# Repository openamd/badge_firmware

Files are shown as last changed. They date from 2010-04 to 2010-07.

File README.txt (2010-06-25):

This project is that of the Next Hope conference's badge, a descendant
of the OpenBeacon Sputnik and Last Hope Badge designs.  An NRF24L01+
radio is connected to either an MSP430F2618 or MSP430F2418 in 80LQFP
or 64LQFP packaging.

For the conference itself, the badge has its FT232RL and USB connector
unpopulated.  These can be added to facilitate MSP430 development on
the badge, such as packet sniffing and injection on the 2.4GHz ISM
band.  For more casual users, an FTDI cable ought to suffice.

The MSP430's bootloader in hardware, so you needn't worry about
bricking the device.  Use a BSL client with 2xx support, such as
goodfet.bsl from http://goodfet.sf.net/ .

Happy Hacking,
--Travis Goodspeed

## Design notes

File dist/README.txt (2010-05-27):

==========================================================
README

This README was built for manufacturing, not for development.  The
following instructions explain how to program the badge from a Windows
workstation with a single GoodFET programmer attached.

-q@theqlabs.com

==========================================================

Hold the Windows button down and press the "R" key
Type "cmd" and press ENTER
type "cd dist" and press ENTER

THEN ...

======================
Drivers
======================

Install vcredist_x86.exe if the "Cannot execute program." error
message is seen.  Drivers for the FTDI chip in the GoodFET programmer
can be found in CDM*.ZIP.

All of these files are in the Drivers folder.

======================
TO SCAN FOR PROGRAMMER
======================

Type "scan.bat" and press ENTER.

NOTE: Scanning is now automatically handled in the other commands.  Just
make sure that one COM port is listed, such as

COM6: (FTDIBUS\COMPORT&VID_0403&PID_6001) Ready

=======================
TO FLASH THE PROGRAMMER
=======================

Type "flashProgrammer.bat" and press ENTER.  This will load the latest
programmer firmware, which is necessary to program the badge.

====================
BADGE BLINK TEST
====================

Type "flashBlink.bat" and press ENTER.  This will blink LED1 and do
nothing else.  This is only to verify that the programmer is properly
wired.

==================
BADGE RADIO TEST
==================

Type "flashBadge.bat" and press ENTER.  This will update the badge
firmware.  You will be asked for a serial number, which should be
between 5,000 and 7,000.

LED1 will blink each time a packet is sent over the radio.  At the
same time, a radio chirp should be seen on 2.481 GHz.  You will also
notice all three leds responding to finger presses on the 8-pin GPIO
header.

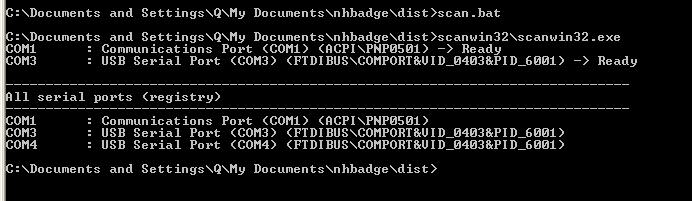
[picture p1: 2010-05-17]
dist/scanExampleImage.JPG

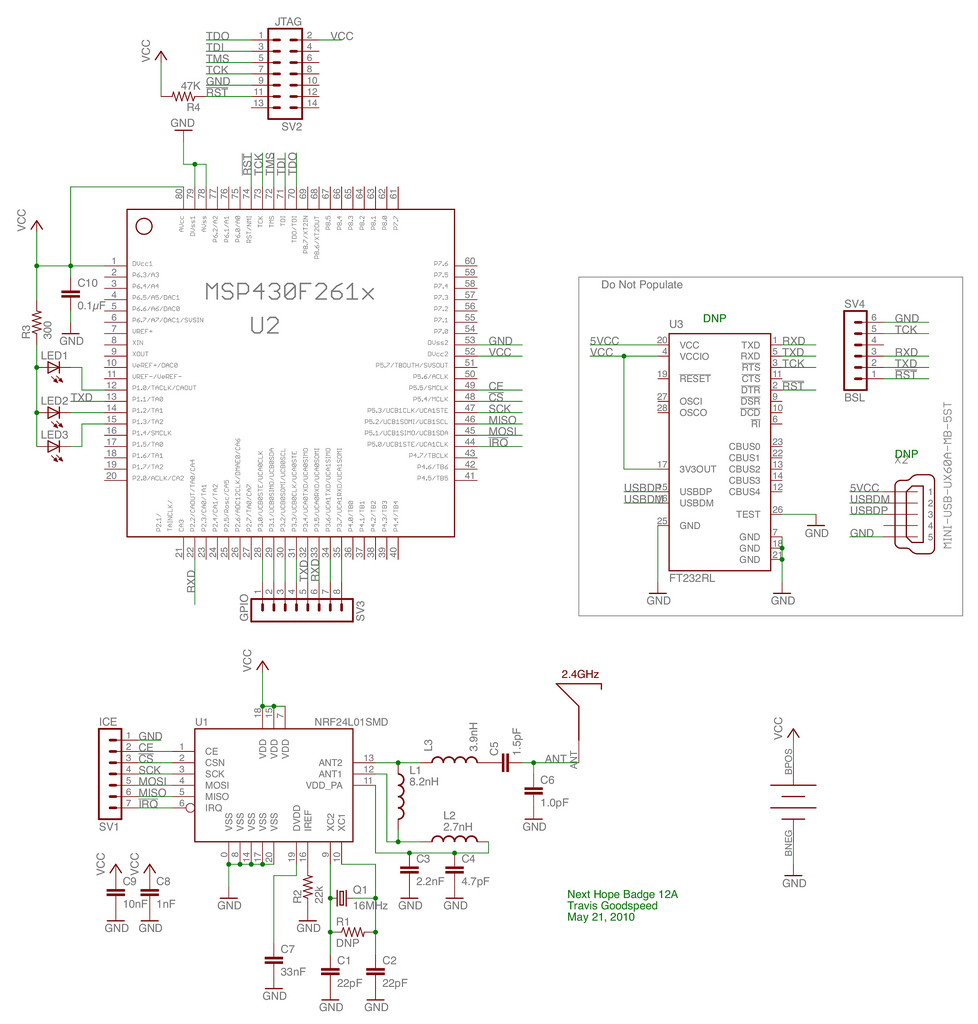
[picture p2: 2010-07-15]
web/nhb12a_schem.jpg

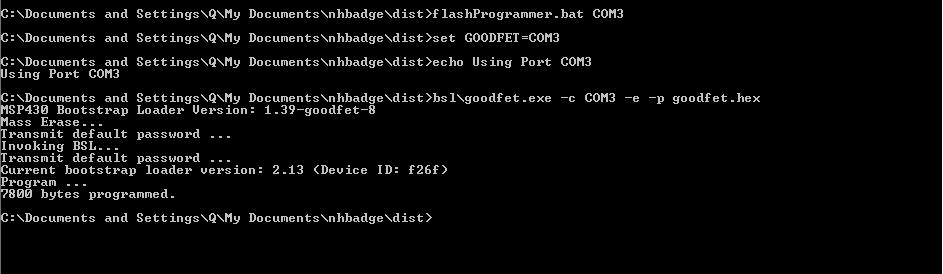
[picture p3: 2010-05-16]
dist/flashProgrammerExampleImage.JPG

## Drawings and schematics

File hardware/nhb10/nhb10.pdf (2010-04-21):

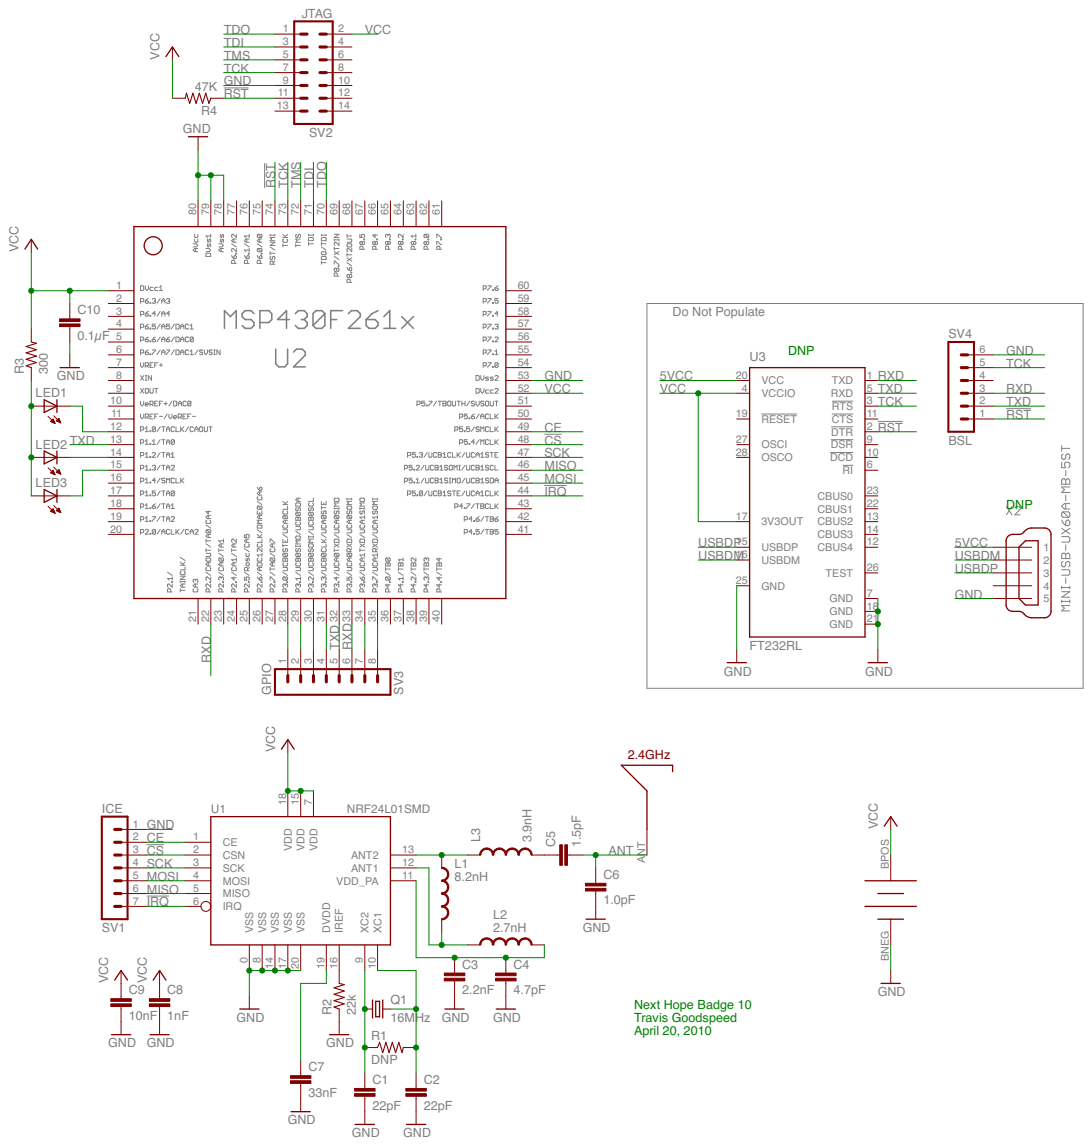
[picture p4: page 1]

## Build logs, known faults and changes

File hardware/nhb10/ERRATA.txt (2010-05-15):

Mext Hope Badge 1.0 Errata
by Travis Goodspeed

ERRATUM 1.

Pin 80 of U2 is AVcc.  It should not be run to ground.  Lift the pin
to correct.

ERRATUM 2.

The battery is located too close to the JTAG port.  Fixed in NHB11 by
moving it further North.

ERRATUM 3.

The programmers shipped to Shanghai with firmware that is not
compatible with the new MSP430 chips.  New firmware needs to be
flashed, and a new client needs to be used.

ERRATUM 4.

The TEST pin of the FTDI should be tied to GND.  Leaving it floating
makes the device non-functional unless you are lucky enough to have a
solder bridge.

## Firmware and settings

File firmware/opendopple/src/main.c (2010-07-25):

/***************************************************************
 *
 * OpenBeacon.org - main entry, CRC, behaviour
 *
 * Copyright 2006 Milosch Meriac <meriac@openbeacon.de>
 * Ported to MSP430 by Travis Goodspeed <travis@tnbelt.com>
 *
 ***************************************************************/

/*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
    You should have received a copy of the GNU General Public License along
    with this program; if not, write to the Free Software Foundation, Inc.,
    51 Franklin Street, Fifth Floor, Boston, MA 02110-1301 USA.

*/

#define OPENBEACON_ENABLEENCODE

//#include <htc.h> //PICC thing
#include <stdlib.h>
#include "config.h"
#include "timer.h"
#include "xxtea.h"
#include "nRF_CMD.h"
#include "nRF_HW.h"
#include "main.h"
#include "led.h"

#ifndef OID_CODE
  #define OID_CODE 0xbeef1337
#endif

//Missing macros.
//__CONFIG (0x03d4);
//__EEPROM_DATA (0x00, 0x00, 0x00, 0x00, 0x00, 0x00, 0x00 ,0x00);

volatile /* const */ u_int32_t oid = OID_CODE, seed = 0xFFFFFFFF;
u_int32_t seq = 0;
static u_int16_t code_block;

TMacroBeacon g_MacroBeacon = {
  0x02,				// Size
  RF_SETUP | WRITE_REG,		// Setup RF Options
  RFB_RFOPTIONS,

  sizeof (TBeaconEnvelope) + 1,	// Size
  WR_TX_PLOAD			// Transmit Packet Opcode
};

//! Swap byte order of a long.
unsigned long htonl (unsigned long src)
{
  unsigned long res;

  ((unsigned char *) &res)[0] = ((unsigned char *) &src)[3];
  ((unsigned char *) &res)[1] = ((unsigned char *) &src)[2];
  ((unsigned char *) &res)[2] = ((unsigned char *) &src)[1];
  ((unsigned char *) &res)[3] = ((unsigned char *) &src)[0];

  return res;
}

//! Swap byte order of a short.
unsigned short htons (unsigned short src)
{
  unsigned short res;

  ((unsigned char *) &res)[0] = ((unsigned char *) &src)[1];
  ((unsigned char *) &res)[1] = ((unsigned char *) &src)[0];

  return res;
}

#define SHUFFLE(a,b) 	tmp=g_MacroBeacon.env.datab[a];\
			g_MacroBeacon.env.datab[a]=g_MacroBeacon.env.datab[b];\
			g_MacroBeacon.env.datab[b]=tmp;

void shuffle_tx_byteorder (void) {
  unsigned char tmp;

  SHUFFLE (0 + 0, 3 + 0);
  SHUFFLE (1 + 0, 2 + 0);
  SHUFFLE (0 + 4, 3 + 4);
  SHUFFLE (1 + 4, 2 + 4);
  SHUFFLE (0 + 8, 3 + 8);
  SHUFFLE (1 + 8, 2 + 8);
  SHUFFLE (0 + 12, 3 + 12);
  SHUFFLE (1 + 12, 2 + 12);
}

unsigned short crc16 (const unsigned char *buffer, unsigned char size){
  unsigned short crc = 0xFFFF;
  if (buffer) {
    while (size--) {
      crc = (crc >> 8) | (crc << 8);
      crc ^= *buffer++;
      crc ^= ((unsigned char) crc) >> 4;
      crc ^= crc << 12;
      crc ^= (crc & 0xFF) << 5;
    }
  }
  return crc;
}

void dopplegang();

void store_incremented_codeblock (void) {
  if (code_block < 0xFFFF) {
    code_block++;
    //EEPROM_WRITE (0, (u_int8_t) (code_block));
    sleep_jiffies (10 * TIMER1_JIFFIES_PER_MS);
    //EEPROM_WRITE (1, (u_int8_t) (code_block >> 8));
    sleep_jiffies (10 * TIMER1_JIFFIES_PER_MS);
  }
}

//TODO move this to a separate header.
void msp430_init_dco();

//! Returns 1 if NRF is connected.
int nrf_ready(){
  char channel=81;
  nRFCMD_RegWrite(5,&channel,1);
  channel=12;
  nRFCMD_RegRead(5,&channel,1);
  
  return channel==81;
}


int openbeacon();

int main (){
  // Stop WDT
  WDTCTL = WDTPW + WDTHOLD;
  
  //LED setup
  PLEDDIR=LEDBITS;
  PLED|=LEDBITS;
  
  PDIR=MOSI+SCK+CSN+CE;//Radio outputs
  POUT=CSN; //chip unselected, radio off.
  
  //Load OID from Info Flash
  // oid=((long*) 0xFFB0)[0];
  oid = OID_CODE;  

  do{
    LED1_LIT;
    LED2_LIT;
    LED3_LIT;
    nRFCMD_Init ();
  }while(!nrf_ready());
  led_startup();
  
  
  //Start broadcasting.
  openbeacon();

  return 0;
}


//! Entry point to the openbeacon app.
int openbeacon(){
  u_int8_t i, status;
  u_int16_t crc=0;
  u_int8_t oldp3=0xFF;
  
  nRFCMD_Init ();
  
  
  // increment code block after power cycle
  ((unsigned char *) &code_block)[0] = EEPROM_READ (0);
  ((unsigned char *) &code_block)[1] = EEPROM_READ (1);
  store_incremented_codeblock ();

  seq = crc ^ oid ^ seed;
  srand (crc16 ((unsigned char *) &seq, sizeof (seq)));

  // increment code blocks to make sure that seq is higher or equal after battery
  // change
  seq = 0; //((u_int32_t)(code_block-1)) << 16;

  i = 0;
  //if (code_block != 0xFFFF)  //Adds security.
    while (1){
      //Step transmit power.
      g_MacroBeacon.rf_setup = NRF_RFOPTIONS | ((i & 3) << 1);
      g_MacroBeacon.env.pkt.hdr.size = sizeof (TBeaconTracker);
      
      g_MacroBeacon.env.pkt.hdr.proto = RFBPROTO_BEACONTRACKER;
      // TODO g_MacroBeacon.env.pkt.flags = CONFIG_PIN_SENSOR ? 0 : RFBFLAGS_SENSOR;
      //g_MacroBeacon.env.pkt.flags = P3IN;
      //Strength field, also describes TX power.
      g_MacroBeacon.env.pkt.strength = 0x55 * (i & 0x3);
      g_MacroBeacon.env.pkt.seq = htonl (seq++);
      g_MacroBeacon.env.pkt.oid = htonl (oid);
      g_MacroBeacon.env.pkt.reserved = CALBC1_16MHZ|(CALDCO_16MHZ<<8);
      crc = crc16 (g_MacroBeacon.env.datab,
		   sizeof (g_MacroBeacon.env.pkt) -
		   sizeof (g_MacroBeacon.env.pkt.crc));
      g_MacroBeacon.env.pkt.crc = htons (crc);
      
      /*
      g_MacroBeacon.env.pkt.hdr.size = ((char*) &g_MacroBeacon.env.pkt)[-1];
      ((char*) &g_MacroBeacon.env.pkt)[-1]=0xde;
      */
      
      // update code_block so on next power up
      // the seq will be higher or equal
      crc = seq >> 16;
      if (crc == 0xFFFF)
	break;
      if (crc == code_block)
	store_incremented_codeblock ();
      
      // encrypt my data
      #ifdef CONFIG_TEA_ENABLEENCODE
      shuffle_tx_byteorder ();
      xxtea_encode ();
      shuffle_tx_byteorder ();
      #endif
      
      
      // Indicate touch sensor.  This must be done before P3 refresh below.
      LED1_DIM;
      LED2_DIM;
      LED3_DIM;
      
      // Multitouch! (strong)
      /*
      if((P3IN^0xFF)&0xC0)
	LED3_LIT;
      if((P3IN^0xFF)&0x18)
	LED2_LIT;
      if((P3IN^0xFF)&0x03)
	LED1_LIT;
      */
      
      
      
      //Reset touch sensor.
      P3OUT=0xFF;
      P3DIR=0xFF;
      
      //Capacitance will change to show status.
      msleep(3);
      P3DIR=0;
      msleep(3);
      
      oldp3=P3IN;
      g_MacroBeacon.env.pkt.flags = oldp3;
      // Multitouch! (strong)
      /* if((oldp3^0xFF)&0x80) */
      /* 	LED3_LIT; */
      /* if((oldp3^0xFF)&0x18) */
      /* 	LED2_LIT; */
      /* if((oldp3^0xFF)&0x01) */
      /* 	LED1_LIT; */
      
      
      //Sleep for a bit while I/O is outbound.
      msleep(1+(rand()&0x3F)); //Bitmasking works, modulus doesn't.  Sign extension?
      
      // send it away
      nRFCMD_Macro ((unsigned char *) &g_MacroBeacon);
      status = (i & 0x7) == 0;
      

      if(status)
	LED1_LIT;
      nRFCMD_Execute (); //Transmit packet held in TX Buffer

      while(!nrf_ready()){
	nRFCMD_Init ();  //Reset radio.
	LED3_LIT;
      }


      if ((oldp3^0xFF)&0x80) {
	dopplegang();
      }
      nRFCMD_Init ();
      
      i++;
    }
  
  // rest in peace
  // when seq counter is exhausted
  LED1_DIM;
  LED2_DIM; 
  LED3_DIM;
  while (1){
    sleep_jiffies (95 * TIMER1_JIFFIES_PER_MS);
    //LED3_LIT;
    sleep_jiffies (5 * TIMER1_JIFFIES_PER_MS);
    //LED3_DIM;
  }
}

//! Macro to receive a packet.
const unsigned char g_MacroRecv[] = {
  0x02, CONFIG | WRITE_REG, NRF_CONFIG_PRIM_RX | NRF_CONFIG_PWR_UP,
  //0x02, STATUS | WRITE_REG, 0x70,	// reset status
  0x00
};


void selftest_body();

//! Alternate reset vector for testing radio.
interrupt(RESERVED0_VECTOR)  //Entry point at 0xFFC0 on MSP430F2618.
selftest_main(){
  //Start stack, because we aren't coming from main().
  asm("mov     #0x3000, r1");
  selftest_body();
}

//! Tests for radio reception, then moves the results into the PC.
void selftest_body(){
  u_int8_t i;
  u_int8_t* packet=(u_int8_t*) 0x3000;  //Packets are stored here.
  u_int8_t status;
  int rxcount=0;
  
  //Blank testing area.
  for(i=0;i<0xff;i++)
    packet[i]=0;
  packet=(u_int8_t*) 0x3020;
  
  // Stop WDT
  WDTCTL = WDTPW + WDTHOLD;
  
  //LED setup
  PLEDDIR=LEDBITS;
  PLED|=LEDBITS;
  
  //Pin directions
  PDIR=MOSI+SCK+CSN+CE;//Radio outputs
  POUT=CSN; //chip unselected, radio off.
  
  
  //Enter receiver mode.
  nRFCMD_InitSniff ();
  nRFCMD_Macro ((unsigned char *) &g_MacroRecv);
  
  
  //Set bytes to 0xFF that must be zero.
  packet[0]=0xFF;
  
  i = 0;
  LED1_DIM;
  while (1){
    
    //Enter receiver mode.
    nRFCMD_InitSniff ();
    nRFCMD_Macro ((unsigned char *) &g_MacroRecv);
  
    
    //Wait a bit.
    LED3_DIM;
    POUT|=CE;
    msleep(300L); //0.1s
    POUT&=~CE;
    LED3_LIT;
    
    
    POUT|=CE;
    //Get the packet.
    POUT&=~CSN;
    nRFCMD_XcieveByte(RD_RX_PLOAD);
    for(i=0;i<16;i++)
      nRFCMD_XcieveByte(0xde);
    POUT|=CSN;

    nRFCMD_RegRead(STATUS,&status,1);
    if(status&0x40){
      // Clear the packet.
      if(rxcount++>3)
	packet[0]=0;
      
      // Clear the flag.
      status=0x40;
      nRFCMD_RegWrite(STATUS,&status,1);
      // Blink led.
      P1OUT^=1;
      // Flush buffer.
      nRFCMD_RegRead(0xE2,&status,0);
      LED2_LIT;
    }
    
  }
}


void dopplegang() {
  u_int8_t i;
  u_int8_t* packet=(u_int8_t*) 0x3000;  //Packets are stored here.
  u_int8_t status;
  int rxcount=0;

  // Stop WDT
  WDTCTL = WDTPW + WDTHOLD;

  //Blank testing area.
  //for(i=0;i<0xff;i++)
  //  packet[i]=0;
  packet=(u_int8_t*) 0x3020;

  LED3_LIT;
  //Enter receiver mode.
  nRFCMD_InitSniff ();
  nRFCMD_Macro ((unsigned char *) &g_MacroRecv);
  
  //Set bytes to 0xFF that must be zero.
  packet[0]=0xFF;
  
  i = 0;
      
  POUT|=CE;
  msleep(300L); //0.1s
  POUT&=~CE;
    
  POUT|=CE;
  //Get the packet.
  POUT&=~CSN;
  nRFCMD_XcieveByte(RD_RX_PLOAD);
  for(i=0;i<16;i++)
    packet[i]=nRFCMD_XcieveByte(0xde);
  POUT|=CSN;
  
  
  // Who are you?  You, it so happens, are me.
  oid = ((uint32_t)packet[11] & 0xff) | 
    ((uint32_t)packet[10] & 0xff) << 8 |
    ((uint32_t)packet[9] & 0xff) << 16 | 
    ((uint32_t)packet[8] & 0xff) << 24;

  // If we didn't dup the sequence number, we'd
  // be too easy to mine after the fact.
  seq = ((uint32_t)packet[7] & 0xff) | 
    ((uint32_t)packet[6] & 0xff) << 8 |
    ((uint32_t)packet[5] & 0xff) << 16 | 
    ((uint32_t)packet[4] & 0xff) << 24;

  LED3_DIM;
}

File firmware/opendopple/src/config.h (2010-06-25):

/***************************************************************
 *
 * OpenBeacon.org - configuration file
 *
 * Copyright 2006 Milosch Meriac <meriac@openbeacon.de>
 * Modifications in 2010 by Travis Goodspeed <travis at radiantmachines.com>
 *
 ***************************************************************/

/*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
    You should have received a copy of the GNU General Public License along
    with this program; if not, write to the Free Software Foundation, Inc.,
    51 Franklin Street, Fifth Floor, Boston, MA 02110-1301 USA.
    	
*/

#include <signal.h>
#include <io.h>
#include <iomacros.h>


#ifndef CONFIG_H
#define CONFIG_H

#define	CONFIG_DEBUG_LED
#define CONFIG_DELAYUS


//TEA is off for now.
//#define CONFIG_TEA_ENABLEENCODE
//#define CONFIG_TEA_ENABLEDECODE

/***************************************************************
 *
 *  CPU peripherals settings
 *
 * configuration:
 *      RA0                     input
 *      RA1     SENSOR          input
 *      RA2     nRF_IRQ         input
 *      RA3     Vpp             input
 *      RA4                     input
 *      RA5                     input
 *
 *      RC0     SCK             output
 *      RC1     MOSI            output
 *      RC2     MISO            input
 *      RC3     CSN             output
 *      RC4     nRF_CE          output
 *      RC5     LED             output
 *
 ***************************************************************/

/*
// PIC pins are weird.  This is deprecated.
#define CONFIG_PIN_SENSOR	RA1
#define CONFIG_PIN_IRQ		RA2

#define CONFIG_PIN_SCK		RC0
#define CONFIG_PIN_MOSI		RC1
#define CONFIG_PIN_MISO		RC2
#define CONFIG_PIN_CSN		RC3
#define CONFIG_PIN_CE		RC4
#define CONFIG_PIN_LED		RC5

#define CONFIG_CPU_XTAL_FREQ	8MHz
#define CONFIG_CPU_TRISA	0x3F
#define CONFIG_CPU_TRISC	0x04
#define CONFIG_CPU_ANSEL	0x00
#define CONFIG_CPU_WPUA		0x02
#define CONFIG_CPU_CMCON0	0x07
#define CONFIG_CPU_OPTION	0x00
#define CONFIG_CPU_OSCCON	0x71
*/

#define PLED P1OUT
#define PLEDDIR P1DIR
#define LEDBITS (BIT0+BIT2+BIT3);
#define LED1_LIT P1OUT&=~BIT0
#define LED2_LIT P1OUT&=~BIT2
#define LED3_LIT P1OUT&=~BIT3
#define LED1_DIM P1OUT|=BIT0
#define LED2_DIM P1OUT|=BIT2
#define LED3_DIM P1OUT|=BIT3


//Pins and I/O
#define IRQ   BIT0
#define MOSI BIT1
#define MISO BIT2
#define SCK  BIT3
#define CSN BIT4
#define CE BIT5


#ifdef p4
#define POUT P4OUT
#define PDIR P4DIR
#define PREN P4REN
#define PIN P4IN
#endif

#ifdef p5
#define POUT P5OUT
#define PDIR P5DIR
#define PREN P5REN
#define PIN P5IN
#endif

// Port definitions, replacing PICC ones.
#define CONFIG_PIN_CSN_HIGH POUT|=CSN
#define CONFIG_PIN_CSN_LOW POUT&=~CSN
#define CONFIG_PIN_CE_HIGH POUT|=CE
#define CONFIG_PIN_CE_LOW POUT&=~CE
#define CONFIG_PIN_MOSI_HIGH POUT|=MOSI
#define CONFIG_PIN_MOSI_LOW POUT&=~MOSI
#define CONFIG_PIN_SCK_HIGH POUT|=SCK
#define CONFIG_PIN_SCK_LOW POUT&=~SCK
#define CONFIG_PIN_MISO (PIN&MISO?1:0)

// TODO fix EEPROM stuff to use info B.
#define EEPROM_READ(x) (0)

/***************************************************************
 *
 *  RF chip settings
 *
 ***************************************************************/

#define CONFIG_DEFAULT_CHANNEL 81

#endif

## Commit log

2010-03-10 NHB10 radio layout.
    [nhb10.sch]
2010-03-10 README file.
    [nhb10.sch]
2010-03-10 About to route the radio.
    [nhb10.brd]
2010-03-10 Routed, about to draw ground planes.
    [nhb10.brd]
2010-03-10 Mostly routed, planes next.
    [nhb10.brd]
2010-04-08 Radio layout complete.
    [nhb10.brd, nhb10.sch]
2010-04-08 MSP430 routed.
    [nhb10.brd, nhb10.sch]
2010-04-08 Optional FT232RL
    [nhb10.brd, nhb10.sch]
2010-04-09 real battery clip.
2010-04-19 badge library
    [nhb10.brd, nhb10.sch]
2010-04-20 Trace antenna complete.
2010-04-20 Trace antenna routed.
    [nhb10.brd, nhb10.sch]
2010-04-20 More vias.
    [nhb10.brd]
2010-04-20 Circle shape, drill hole, extended ground plane.
    [nhb10.brd, nhb10.sch]
2010-04-20 Circle, lanyard hole.
    [nhb10.brd, nhb10.sch]
2010-04-20 Sending for fab.
    [nhb10.brd]
2010-04-21 PDF schematic.
2010-04-21 Centroid file for pick-and-place.
    [nhb10 centroid.csv]
2010-04-21 FTDI cable and PCB Antenna datasheets.
2010-05-06 About to fork timer.c
2010-05-06 Getting closer, just timer.c to go.
2010-05-06 It compiles! Timer not quite right.
2010-05-14 Forked badge for NHB11.
    [nhb11.brd, nhb11.sch]
2010-05-15 NHB10 errata, NHB11 layout.
    [nhb11.brd, nhb11.sch]
2010-05-16 BSL target, fixing the timing.
    [config.h, main.c, msp430x2618.c]
2010-05-16 Timing is all kinds of wrong, but this works.
    [main.c]
2010-05-16 BSL uses comport as specified, erases FET.
2010-05-17 Drivers for Windows.
2010-05-17 Drivers instructions.
2010-05-21 NHB11 gerbers.
    [nhb11.brd, nhb11.sch]
2010-05-21 Forked NHB11 to NHB11b for 64-pin chips.
    [nhb11b.brd, nhb11b.sch]
2010-05-21 NHB11b routed.
    [nhb11b.brd, nhb11b.sch]
2010-05-21 Ready to fab NHB11b.
    [nhb11b.brd, nhb11b.sch]
2010-05-21 NHB11b gerbers.
2010-05-21 11a label.
    [nhb11.sch]
2010-05-23 Fancier LED artwork, longer broadcasts.
2010-05-26 Added __attribute__((packed)) to the packet to prevent 16-bit packing problems.
    [main.c]
2010-05-26 Multitouch works, timer is still a bit wonky.
2010-05-26 Cleaned warnings, removed PIC timer code.
2010-05-26 Multitouch works, timer too.
2010-05-30 Low power mode, proper 2618 erase. A GoodFET patch for the info memory bit might be needed.
2010-05-30 Low power mode works!
2010-05-30 Less sensitive LED. Working on proper sensitivity.
2010-05-30 Sequences now always start at zero and code_block check is skipped. These won't be necessary at TNH unless we change our mind about crypto.
    [main.c]
2010-05-31 NHB12 fork.
    [nhb12.brd, nhb12.sch]
2010-05-31 NHB12B Rename.
    [nhb12b.sch]
2010-06-05 Timer changes.
2010-06-05 Self-test interrupt vector at 0xFFC0.
2010-06-25 Support for generic SPI port.
2010-07-15 Docs moved to other repository.
    [nhb12.brd, nhb12.sch, nhb12b.brd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]
2010-07-15 Assembly instructions.
2010-07-15 This kit docco was printed.

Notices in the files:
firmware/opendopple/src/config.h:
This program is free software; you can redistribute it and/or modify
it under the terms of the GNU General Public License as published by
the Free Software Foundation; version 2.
